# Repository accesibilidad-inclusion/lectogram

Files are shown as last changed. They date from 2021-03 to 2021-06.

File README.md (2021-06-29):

# Lectogram

## Contexto

[Para mayor información acerca de la investigación realizada en el proyecto Envejecimiento activo y discapacidad intelectual haga click aquí](https://wiki.ead.pucv.cl/Proyecto_Envejecimiento_activo_y_discapacidad_intelectual_2020)

En base a un estudio e investigación realizada y los resultados obtenidos a partir de esta, se plantearon una serie de conceptos de diseño con la finalidad de potenciar el envejecimiento activo y la vida independiente de las personas con discapacidad intelectual (DI) en proceso de envejecimiento. 

Este público representa un gran desafío ya que posee un acelerado deterioro de sus capacidades motrices, cognitivas y físicas a comparación con las personas sin DI, lo que se suma a ser una población históricamente vulnerada en la realidad latinoamericana y de Chile.

La propuesta de diseño se desarrolla bajo una perspectiva de diseño centrado en el usuario (DCU), donde se realizan validaciones de los conceptos de diseño con actores relevantes (adulto mayor con DI, cuidadores profesionales y cuidadores familiares) para encontrar los conceptos más aplicables y necesarios en la vida de los usuario, siendo la propuesta **un sistema de apoyo para la comprensión de los espacios** y el lector de pictogramas, resulto ser uno de los tres conceptos con mayor aprobación por adultos con D.I. 

## Apoyo a la interpretación de pictogramas

[Para ingresar al repositorio de GitHub de Lectogram haga click aquí](https://github.com/accesibilidad-inclusion/lectogram/tree/gh-pages)

Lectogram consiste en un **apoyo tecnológico**, que facilita la comprensión de los espacios que lo rodean, identificando lugares específicos y objetos con los que pueden realizar actividades de la vida cotidiana, mediante **apoyos visuales y auditivos**.

Esta diseñado particularmente para adultos con Discapacidad intelectual que se encuentran en etapa de envejecimiento. El apoyo visual consiste en **un set de pictogramas** diseñados específicamente para personas con discapacidad intelectual, enfocados en las tareas del hogar.

El apoyo auditivo funciona a través la interacción con el pictograma, Lectogram entrega un mensaje de voz que ayuda a la realización de actividades relacionadas con el hogar. Lectogram se piensa como un objeto portable y manipulable para el usuario ya que este se tiene que acercar y tener contacto con el pictograma para su activación y entregar el apoyo auditivo instructivo de como hacer las actividad de forma general.

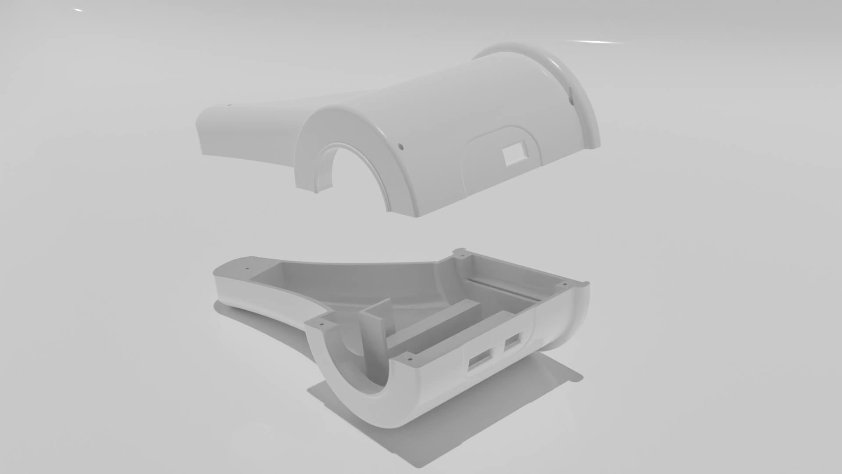
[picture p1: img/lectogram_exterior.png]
Aparato en uso


Vista isométrica

Vista isométrica

### Pictogramas

El uso del aparato va relacionado a la presencia de diversos pictogramas *-que se ubican dentro de la casa-*  que apoyan la realización de actividades cotidianas dentro del hogar, los cuales consisten en una descripción gráfica de la actividad a realizarse.

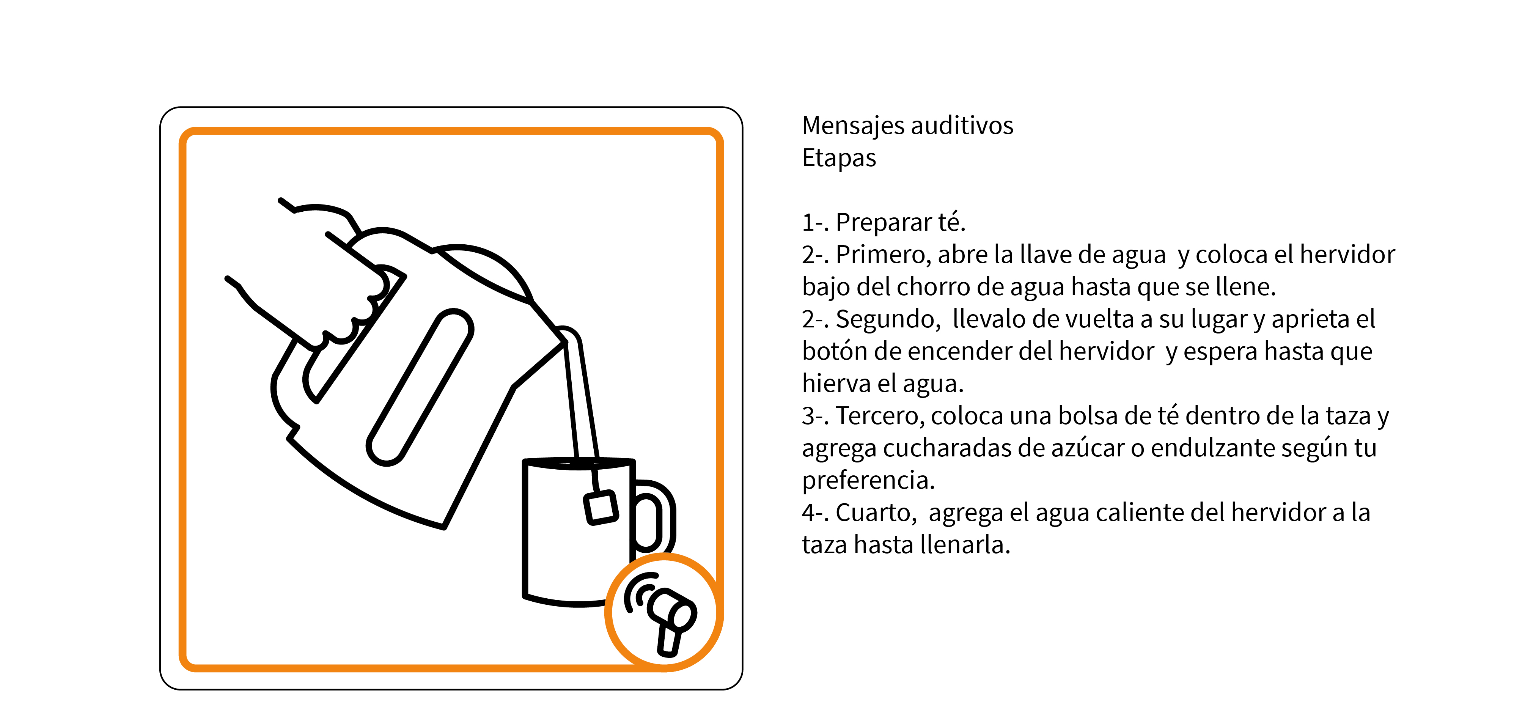
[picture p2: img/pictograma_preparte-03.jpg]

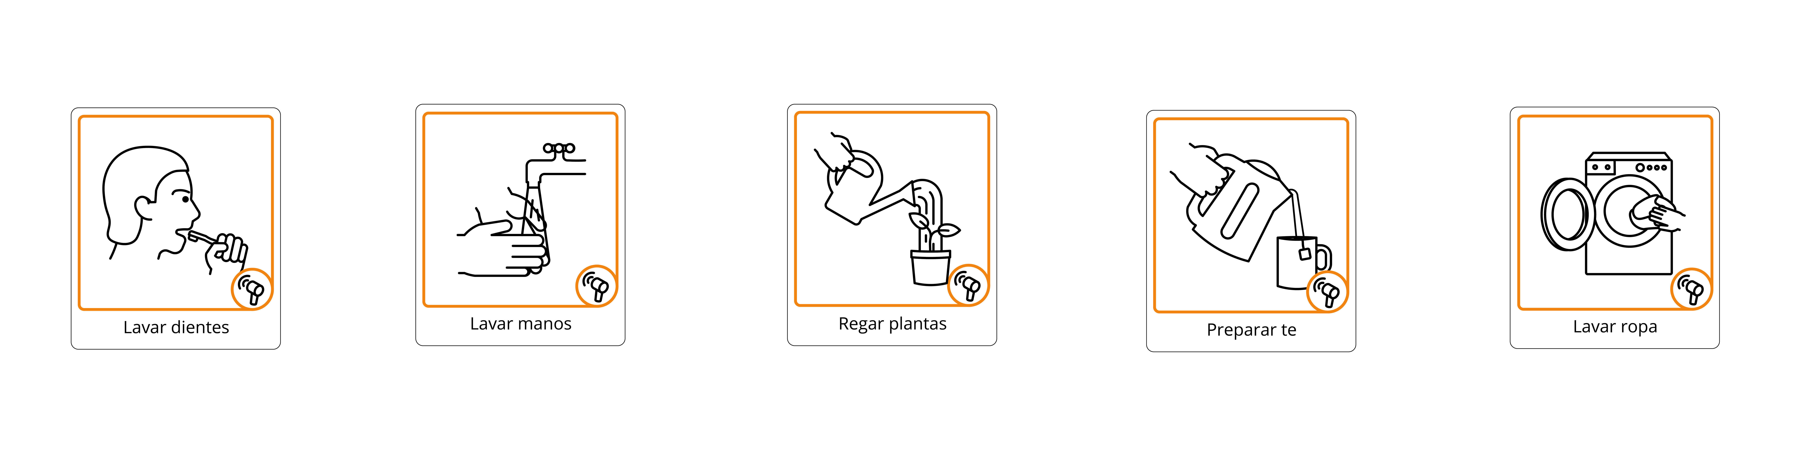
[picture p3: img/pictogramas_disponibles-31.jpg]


### Sistema electrónico

El sistema electrónico del prototipo Lectogram se basa principalmente en la lectura de tarjetas que se ubican en el lugar habitado en forma de pictogramas, esto funciona mediante un **módulo RFID** donde tras la lectura de tarjetas, se confirma la acción con un circulo  en el aro de luz, y luego, la reproducción de las instrucciones, con pausas, que permiten una comprensión clara de la actividad. 

La lectura de tarjetas corresponde a una tecnología de identificación por radio-frecuencia (RFID), la cual se utiliza comúnmente en los ingresos a accesos de edificios con seguridad, y también en versiones a larga distancia se puede encontrar en los 'tag' que utilizan los autos en autopistas de ciudades.

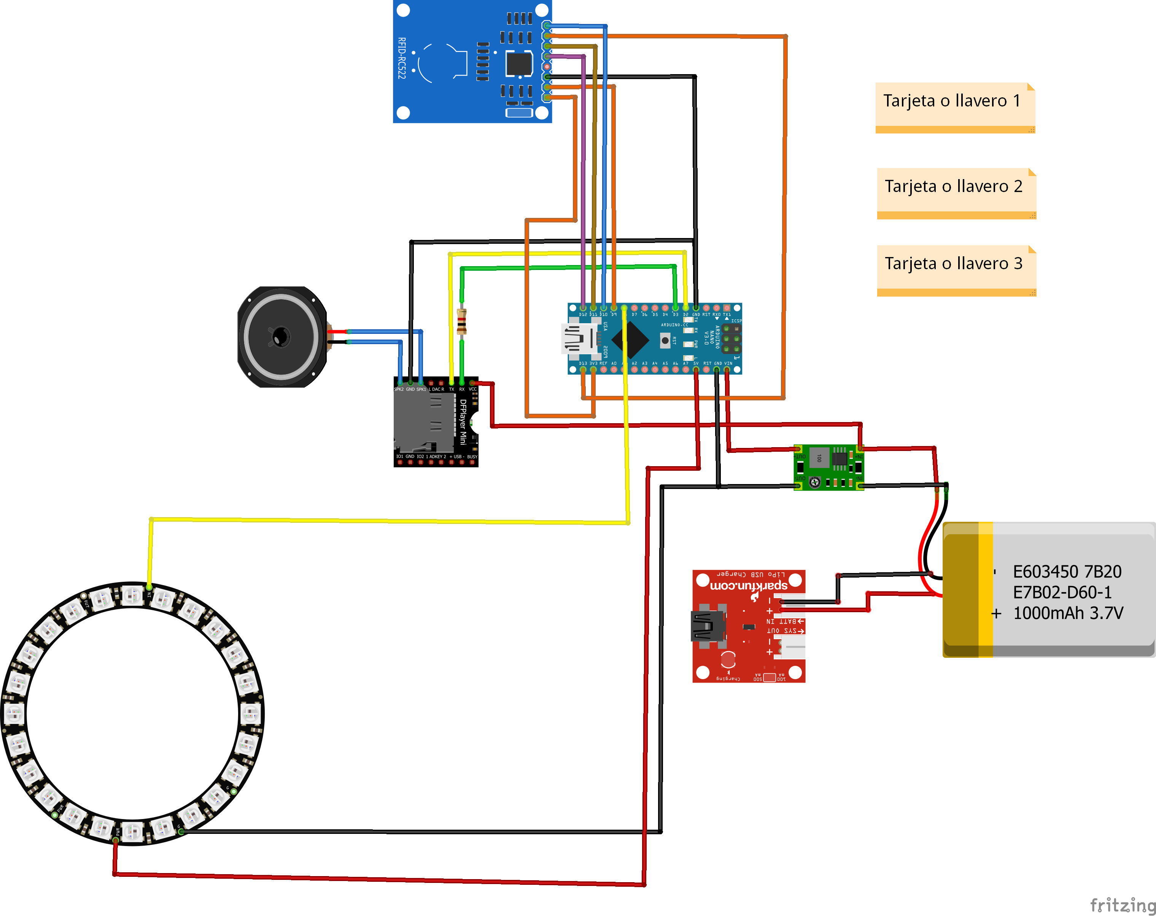
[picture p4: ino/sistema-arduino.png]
Sistema electrónico
*En la imagen se muestra el sistema electrónico del aparato para su funcionamiento*

[Para mayor información acerca del trabajo realizado sobre el primer prototipo formal de Lectogram  haga click aquí](https://wiki.ead.pucv.cl/Proyecto_Fondecyt:_Apoyos_a_la_vida_independiente)

## Validación interna

Tras la revisión del primer prototipo formal, se propone un proceso de validación, una evaluación que conste de tres niveles, comenzando con una **validación interna por parte del equipo desarrollador de los prototipos**, para luego dar cabida a una **evaluación por parte del G.A *-grupo asesor-*** y finalmente terminar con una **evaluación en residencias**. 

Lo que se busca con esto, es que entre evaluaciones se puedan ir aplicando mejoras según las experiencias de cada usuario que lo testee, y que de esta manera, pueda llegar a un estado óptimo en cuanto a diseño y funcionalidad. 

Tras la revisión inicial, se detectan los siguientes **problemas**: 

1. El aro de luz muestra colores que se encuentran asignados al azar, por lo que no se comprende la funcionalidad de estas. 

2. Velocidad de los audios, las instrucciones pasan una a continuación de otra sin pausas entre estas, entorpeciendo la comprensión.

3. El volumen del artefacto es muy bajo.

Para los que se aplican las siguientes **mejoras**:

1. Las instrucciones por audio se dividirán por los pasos que cada actividad contiene, otorgándole pausas a esta y facilitando la comprensión de cada tarea.

2. El aro de luz verificará el avance de las instrucciones, mediante el avance de luz en conjunto al avance de cada instrucción. 
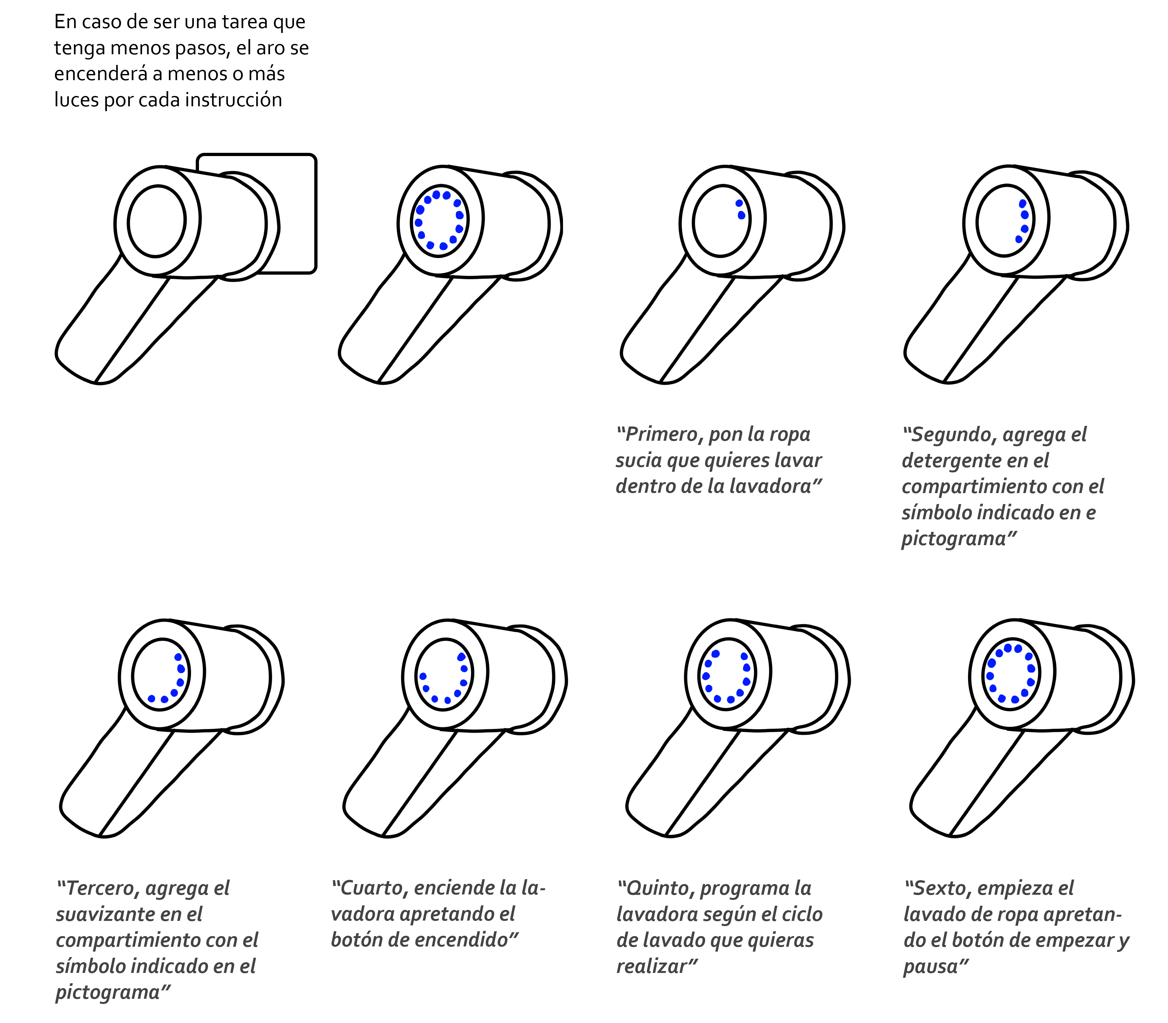
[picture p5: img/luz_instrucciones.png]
Verificación de actividades mediante luz
*En la imagen se muestra la secuencia que seguiría el aro de luz en conjunto con la entrega de la instrucción*

3. Categorización de las zonas de la casa por colores establecidos al momento de escanear y reconocer los espacios en que se encuentran cada pictograma.
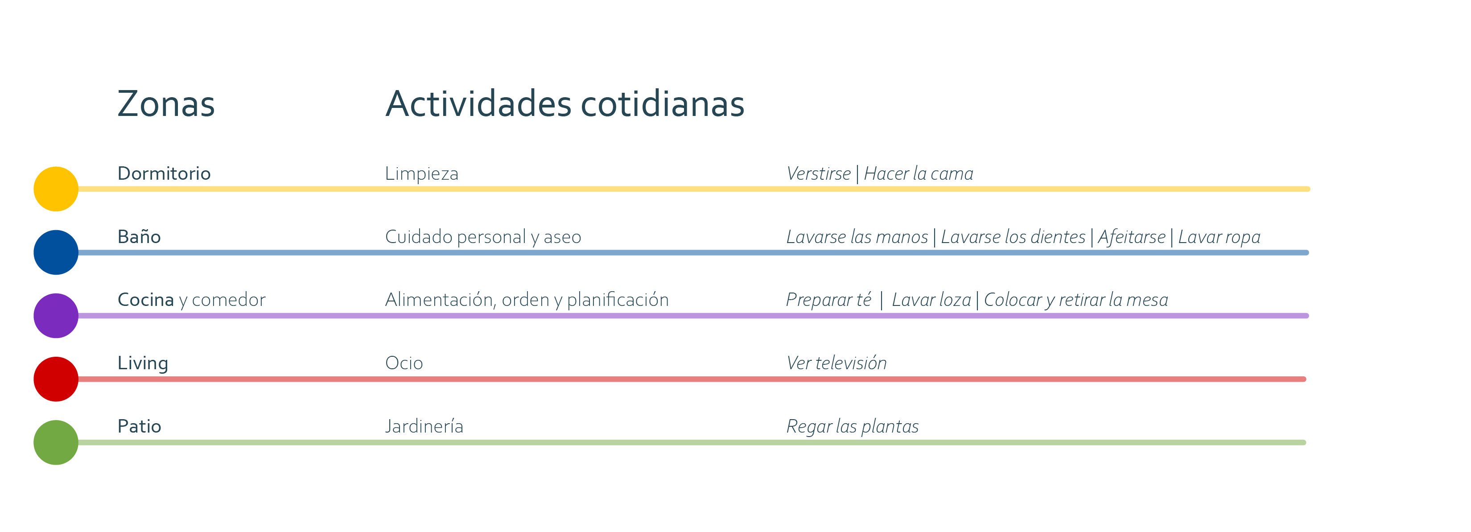
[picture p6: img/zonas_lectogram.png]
Categorización de zonas
*En la imagen se muestra la categorización de zonas de la casa*

4. Re-diseño de la carcasa para lograr un mejor ensamble de esta y generar en ella un  espacio  destinado al sistema electrónico. 
Vista isométrica del aparato
*El re-diseño de la carcasa se plantea tras problemas con el acople del sistema electrónico,  ya que el interior no considera un espacio destinado a la electrónica, por lo que el armado del prototipo resulta muy complicado e implica descomponer el módulo.*

Vista isométrica del aparato
*Paralelamente, la carcasa se compone de dos piezas simétricas, que no presentan algún tipo de ensamble que pueda conectar ambas, por lo que para las primeras pruebas que se realizaron, se utilizó silicona caliente, luego de pruebas con otros materiales que pudieran resultar más discretos, sin resultados positivos.*

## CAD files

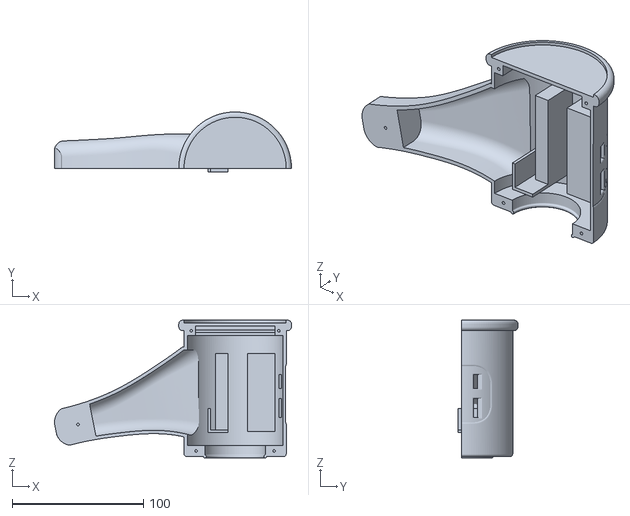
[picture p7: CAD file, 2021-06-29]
3d/parte inferior_lectogram.stl
180.8 x 45.8 x 105.0

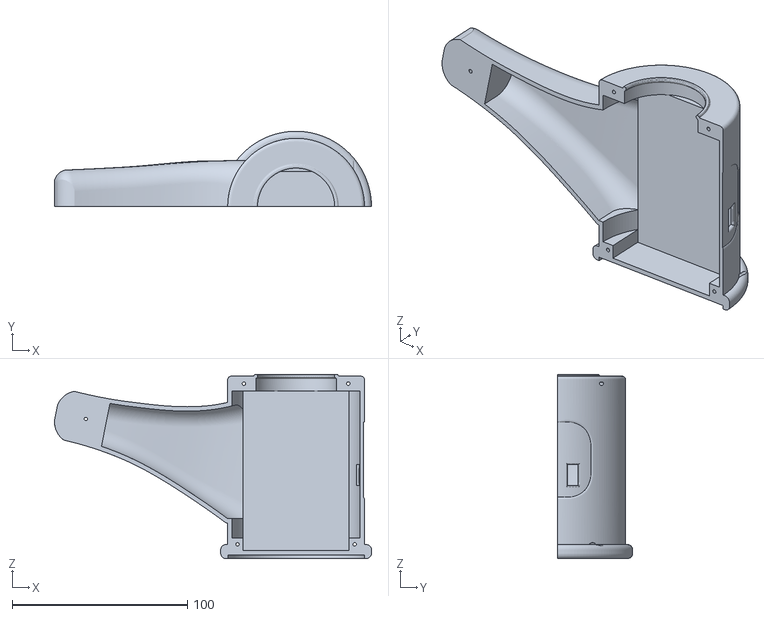
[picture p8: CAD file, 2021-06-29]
3d/parte superior_lectogram.stl
180.8 x 43.0 x 105.0

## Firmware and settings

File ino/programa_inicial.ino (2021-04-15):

#include <SPI.h>
#include <MFRC522.h>
#include "SoftwareSerial.h"
#include "DFRobotDFPlayerMini.h"

#include "SoftwareSerial.h"
#include "DFRobotDFPlayerMini.h"

#include <Adafruit_NeoPixel.h>

#define PIN 6 //Designamos nuestro pin de datos
#define NUMPIXELS      16 //Designamos cuantos pixeles tenemos en nuestra cinta led RGB
Adafruit_NeoPixel pixels = Adafruit_NeoPixel(NUMPIXELS, PIN, NEO_GRB + NEO_KHZ800);
// IMPORTANTE: Para reducir el riesgo de dañar los pixeles de la cinta, añada un condensador de 1000 uF a través de
// los cables de alimentación de la cinta, agregue una resistencia de 300-500 Ohm en la entrada de datos del primer pixel
// Y reduzca la distancia entre Arduino y el primera pixel.


#define RST_PIN  9    //Pin 9 para el reset del RC522
#define SS_PIN  10   //Pin 10 para el SS (SDA) del RC522
MFRC522 mfrc522(SS_PIN, RST_PIN); ///Creamos el objeto para el RC522

//SoftwareSerial mySoftwareSerial(10, 11); // RX, TX
SoftwareSerial mySoftwareSerial(2, 3); // RX, TX
DFRobotDFPlayerMini myDFPlayer;
char command;
int pausa = 0;
int delayval = 50; // Pausa
uint32_t rojo = pixels.Color(150,0,0);
uint32_t verde = pixels.Color(0,150,0);
uint32_t azul = pixels.Color(0,0,150);
uint32_t apagado = pixels.Color(0,0,0);
uint32_t amarillo = pixels.Color(150,150,0);
uint32_t morado = pixels.Color(150,0,150);
uint32_t celeste = pixels.Color(0,150,150);
uint32_t blanco = pixels.Color(150,150,150);
   
void setup() 
{
pixels.begin(); 
mySoftwareSerial.begin(9600); //Comunicacao serial com o modulo
Serial.begin(115200);//Inicializa a serial do Arduino
Serial.println();//Verifica se o modulo esta respondendo e se o
Serial.println(F("DFRobot DFPlayer Mini"));
Serial.println(F("Initializing DFPlayer module ... Wait!"));
if (!myDFPlayer.begin(mySoftwareSerial))
{
  Serial.println(F("Not initialized:"));
  Serial.println(F("1. Check the DFPlayer Mini connections"));
  Serial.println(F("2. Insert an SD card"));
  while (true);
}
Serial.println();
Serial.println(F("DFPlayer Mini module initialized!"));
myDFPlayer.setTimeOut(500); //Timeout serial 500ms
myDFPlayer.volume(25); //Volume máx 30
myDFPlayer.EQ(0); //Equalizacao normal
//menu_opcoes();

SPI.begin();        //Iniciamos el Bus SPI
mfrc522.PCD_Init(); // Iniciamos el MFRC522
Serial.println("Control de acceso:");
command='6';                                    //bienvenido al sistema
command = command - 48;
myDFPlayer.play(command);

for(int i=0;i<NUMPIXELS;i++)
   {
    pixels.setPixelColor(i, celeste); // Brillo moderado en rojo
    pixels.show();   // Mostramos y actualizamos el color del pixel de nuestra cinta led RGB
    delay(delayval); // Pausa por un periodo de tiempo (en milisegundos).
    pixels.setPixelColor(i, apagado); // Brillo moderado en azul
    pixels.show();   // Mostramos y actualizamos el color del pixel de nuestra cinta led RGB
    delay(delayval); // Pausa por un periodo de tiempo (en milisegundos).
   } 

for(int i=0;i<NUMPIXELS;i++)
   {
    pixels.setPixelColor(i, verde); // Brillo moderado en rojo
    pixels.show();   // Mostramos y actualizamos el color del pixel de nuestra cinta led RGB
    delay(delayval); // Pausa por un periodo de tiempo (en milisegundos).
    pixels.setPixelColor(i, apagado); // Brillo moderado en azul
    pixels.show();   // Mostramos y actualizamos el color del pixel de nuestra cinta led RGB
    delay(delayval); // Pausa por un periodo de tiempo (en milisegundos).
   } 
}

byte ActualUID[4]; //almacenará el código del Tag leído
byte Usuario1[4]= {0xB9, 0x99, 0x45, 0xE8} ; //código del usuario 1
byte Usuario2[4]= {0x6C, 0x38, 0x5A, 0x89} ; //código del usuario 2
byte Usuario3[4]= {0x0D, 0x8E, 0x59, 0x89} ; //código del usuario 3
byte Usuario4[4]= {0xBA, 0xFF, 0xCC, 0x73} ; //código del usuario 4
byte Usuario5[4]= {0xF2, 0x76, 0x5A, 0x89} ; //código del usuario 5

/*
 * TARJETAS
1-> B9 99 45 E8
2-> 6C 38 5A 89
3-> 0D 8E 59 89
4-> BA FF CC 73
5-> F2 76 5A 89


0001_bienvenido
0002_living
0003_baño
0004_cocina
0005_balcon
0006_pieza
 */

void loop()
{
//---------------------------------------------------selección de audios
if ( mfrc522.PICC_IsNewCardPresent())  // Revisamos si hay nuevas tarjetas  presentes
        {  
      //Seleccionamos una tarjeta
            if ( mfrc522.PICC_ReadCardSerial()) 
            {
                  // Enviamos serialemente su UID
                  Serial.print(F("Card UID:"));
                  for (byte i = 0; i < mfrc522.uid.size; i++) 
                  {
                          Serial.print(mfrc522.uid.uidByte[i] < 0x10 ? " 0" : " ");
                          Serial.print(mfrc522.uid.uidByte[i], HEX);   
                          ActualUID[i]=mfrc522.uid.uidByte[i];          
                  } 
                  Serial.print("     ");                 
                  //comparamos los UID para determinar si es uno de nuestros usuarios  
                  /*
                   * INGRESO DE USUARIOS (TARJETAS) Y SUS DISTINTOS COMMAND, QUE ACTIVARÁN LOS DISTINTOS SONIDOS
                   */
                  if(compareArray(ActualUID,Usuario1)) //------------------------------------------usuario 1
                    {
                   // Serial.println("Acceso concedido...");
                    command='1';
                    LED_ROJO();
                    }
                  else if(compareArray(ActualUID,Usuario2)) //-------------------------------------usuario 2
                    {
                   // Serial.println("Acceso concedido...");
                    command='2';  
                    LED_AZUL();                  
                    }
                  else if(compareArray(ActualUID,Usuario3)) //-------------------------------------usuario 2
                    {
                   // Serial.println("Acceso concedido...");
                    command='3';
                    LED_AMARILLO();                    
                    }
                   else if(compareArray(ActualUID,Usuario4)) //-------------------------------------usuario 2
                    {
                   // Serial.println("Acceso concedido...");
                    command='4';
                    LED_VERDE();                    
                    }
                   else if(compareArray(ActualUID,Usuario5)) //-------------------------------------usuario 2
                    {
                   // Serial.println("Acceso concedido...");
                    command='5'; 
                    LED_CELESTE();                  
                    }
                  else
                   { Serial.println("Acceso denegado...");}
                                   
                  mfrc522.PICC_HaltA(); // Terminamos la lectura de la tarjeta tarjeta  actual
                  if ((command >= '1') && (command <= '9'))
                    {
                    Serial.print("Music reproduction");
                    Serial.println(command);
                    command = command - 48;
                    myDFPlayer.play(command);
                   // menu_opcoes();
                    }
            }            
        }        
}
 boolean compareArray(byte array1[],byte array2[])
{
  if(array1[0] != array2[0])return(false);
  if(array1[1] != array2[1])return(false);
  if(array1[2] != array2[2])return(false);
  if(array1[3] != array2[3])return(false);
  return(true);
}

void LED_ROJO()
{
  for(int i=0;i<NUMPIXELS;i++)
   {
    pixels.setPixelColor(i, rojo); // Brillo moderado en rojo
    pixels.show();   // Mostramos y actualizamos el color del pixel de nuestra cinta led RGB
    delay(delayval); // Pausa por un periodo de tiempo (en milisegundos).
    pixels.setPixelColor(i, apagado); // Brillo moderado en azul
    pixels.show();   // Mostramos y actualizamos el color del pixel de nuestra cinta led RGB
    delay(delayval); // Pausa por un periodo de tiempo (en milisegundos).
   }  
}
void LED_VERDE()
{
  for(int i=0;i<NUMPIXELS;i++)
   {
    pixels.setPixelColor(i,verde); // Brillo moderado en rojo
    pixels.show();   // Mostramos y actualizamos el color del pixel de nuestra cinta led RGB
    delay(delayval); // Pausa por un periodo de tiempo (en milisegundos).
    pixels.setPixelColor(i, apagado); // Brillo moderado en azul
    pixels.show();   // Mostramos y actualizamos el color del pixel de nuestra cinta led RGB
    delay(delayval); // Pausa por un periodo de tiempo (en milisegundos).
   }  
}

void LED_AZUL()
{
  for(int i=0;i<NUMPIXELS;i++)
   {
    pixels.setPixelColor(i, azul); // Brillo moderado en rojo
    pixels.show();   // Mostramos y actualizamos el color del pixel de nuestra cinta led RGB
    delay(delayval); // Pausa por un periodo de tiempo (en milisegundos).
    pixels.setPixelColor(i, apagado); // Brillo moderado en azul
    pixels.show();   // Mostramos y actualizamos el color del pixel de nuestra cinta led RGB
    delay(delayval); // Pausa por un periodo de tiempo (en milisegundos).
   }  
}
void LED_AMARILLO()
{
  for(int i=0;i<NUMPIXELS;i++)
   {
    pixels.setPixelColor(i, amarillo); // Brillo moderado en rojo
    pixels.show();   // Mostramos y actualizamos el color del pixel de nuestra cinta led RGB
    delay(delayval); // Pausa por un periodo de tiempo (en milisegundos).
    pixels.setPixelColor(i, apagado); // Brillo moderado en azul
    pixels.show();   // Mostramos y actualizamos el color del pixel de nuestra cinta led RGB
    delay(delayval); // Pausa por un periodo de tiempo (en milisegundos).
   }  
}
void LED_MORADO()
{
  for(int i=0;i<NUMPIXELS;i++)
   {
    pixels.setPixelColor(i,morado); // Brillo moderado en rojo
    pixels.show();   // Mostramos y actualizamos el color del pixel de nuestra cinta led RGB
    delay(delayval); // Pausa por un periodo de tiempo (en milisegundos).
    pixels.setPixelColor(i, apagado); // Brillo moderado en azul
    pixels.show();   // Mostramos y actualizamos el color del pixel de nuestra cinta led RGB
    delay(delayval); // Pausa por un periodo de tiempo (en milisegundos).
   }  
}
void LED_CELESTE()
{
  for(int i=0;i<NUMPIXELS;i++)
   {
    pixels.setPixelColor(i, celeste); // Brillo moderado en rojo
    pixels.show();   // Mostramos y actualizamos el color del pixel de nuestra cinta led RGB
    delay(delayval); // Pausa por un periodo de tiempo (en milisegundos).
    pixels.setPixelColor(i, apagado); // Brillo moderado en azul
    pixels.show();   // Mostramos y actualizamos el color del pixel de nuestra cinta led RGB
    delay(delayval); // Pausa por un periodo de tiempo (en milisegundos).
   }  
}

/*
//Waits for data entry via serial
while (Serial.available() > 0)
{
  command = Serial.read();
  
  //Reproduction
  //Stop
  
  if (command == 's') //------------------------STOP
  {
    myDFPlayer.stop();
    Serial.println("Music Stopped!");
    menu_opcoes();
  }
  
  //Pausa/Continua a musica
  if (command == 'p') //------------------------PAUSA
  {
  pausa = !pausa;
  if (pausa == 0)
  {
  Serial.println("Continue...");
  myDFPlayer.start();
  }
  
  if (pausa == 1)
  {
  Serial.println("Music Paused!");
  myDFPlayer.pause();
  }
  
  menu_opcoes();
  }
  
  
  //Increases volume
  if (command == '+')  //---------------------VOL+
  {
    myDFPlayer.volumeUp();
    Serial.print("Current volume:");
    Serial.println(myDFPlayer.readVolume());
    menu_opcoes();
  }
  
  if (command == '<') //---------------------ANTERIOR
  {
    myDFPlayer.previous();
    Serial.println("Previous:");
    Serial.print("Current track:");
    Serial.println(myDFPlayer.readCurrentFileNumber()-1);
    menu_opcoes();
  }
  
  if (command == '>') //---------------------SGTE
  {
    myDFPlayer.next();
    Serial.println("next:");
    Serial.print("Current track:");
    Serial.println(myDFPlayer.readCurrentFileNumber()+1);
    menu_opcoes();
  }
  
  //Decreases volume
  if (command == '-')
  {
    myDFPlayer.volumeDown();
    Serial.print("Current Volume:");
    Serial.println(myDFPlayer.readVolume());
    menu_opcoes();
  }

}
}

void menu_opcoes()
{
  Serial.println();
  Serial.println(F("=================================================================================================================================="));
  Serial.println(F("Commands:"));
  Serial.println(F(" Presenta su tarjeta para reproducir audio"));
  Serial.println(F(" [s] Detiene reproducción"));
  Serial.println(F(" [p] pause/continue music"));
  Serial.println(F(" [+ or -] increases or decreases the volume"));
  Serial.println(F(" [< or >] forwards or backwards the track"));
  Serial.println();
  Serial.println(F("================================================================================================================================="));
} */


//Hola. test de commit

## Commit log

2021-03-27 carpetas varias
    [lectogram.fzz, pictograma-a.obj, pictograma-b.obj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]
2021-03-28 IMG sistema arduino
2021-04-01 redirección de imagenes
2021-04-15 commit test
    Hola esto es un test para probar los commit en este rep.
2021-06-29 propuesta final
    [parte inferior_lectogram.stl, parte superior_lectogram.stl, pictograma-a.obj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]
